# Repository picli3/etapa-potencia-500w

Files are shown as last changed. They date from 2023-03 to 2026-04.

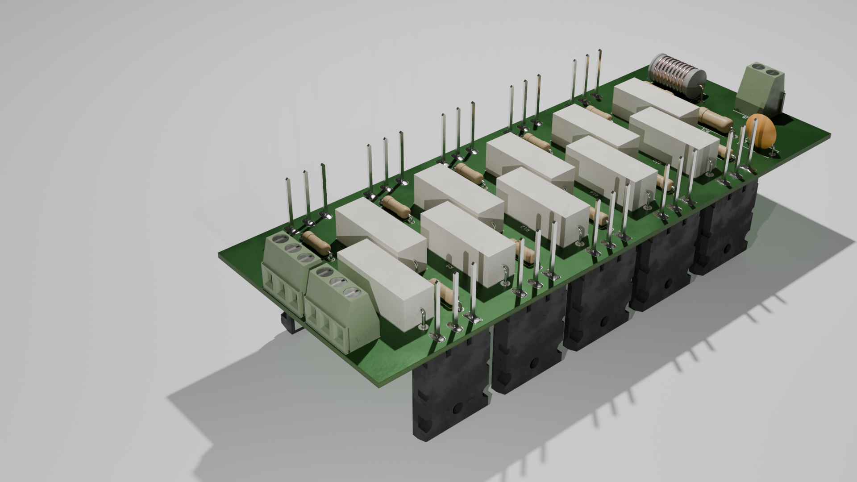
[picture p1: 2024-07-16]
doc/etapa-de-potencia_5.png

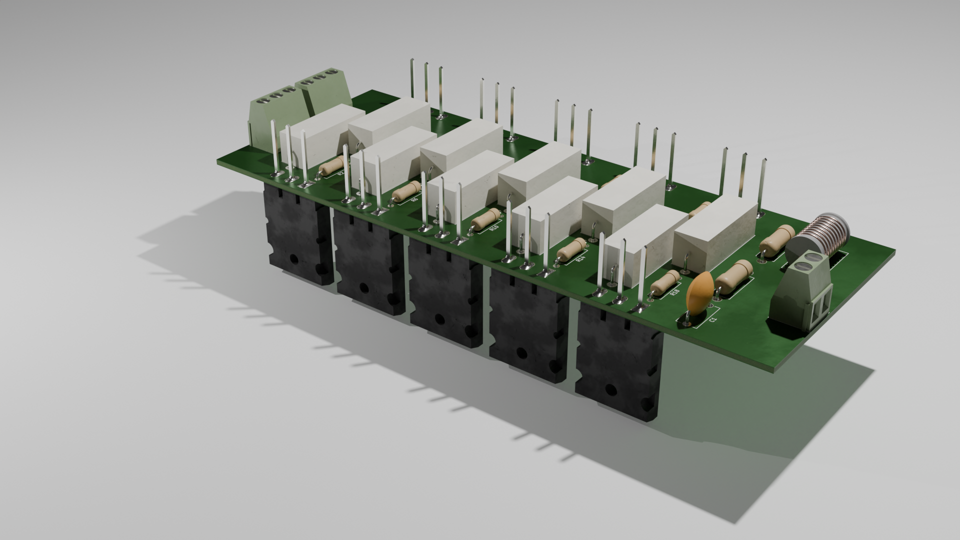
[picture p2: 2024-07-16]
doc/etapa-de-potencia_4.png

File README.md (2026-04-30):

# etapa-potencia-500w

Barra de potencia de audio con múltiples transistores en paralelo, pensada para entregar alta corriente y robustez térmica en amplificadores de gran potencia.

## Qué incluye
- esquemáticos o archivos de diseño en KiCad
- PCB o documentación asociada
- base reutilizable para análisis, fabricación o mejora del proyecto

## Propósito general
Este repositorio busca concentrar el diseño de hardware del proyecto en un formato editable y reutilizable, facilitando pruebas, documentación y futuras iteraciones del circuito.

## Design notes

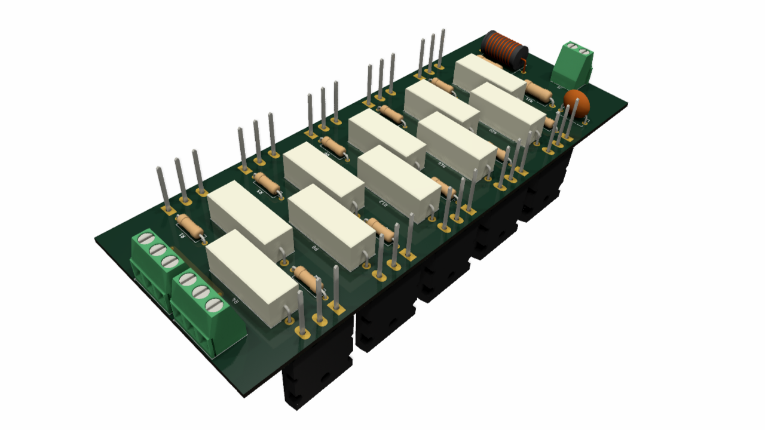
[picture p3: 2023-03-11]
doc/etapa-de-potencia_1.png

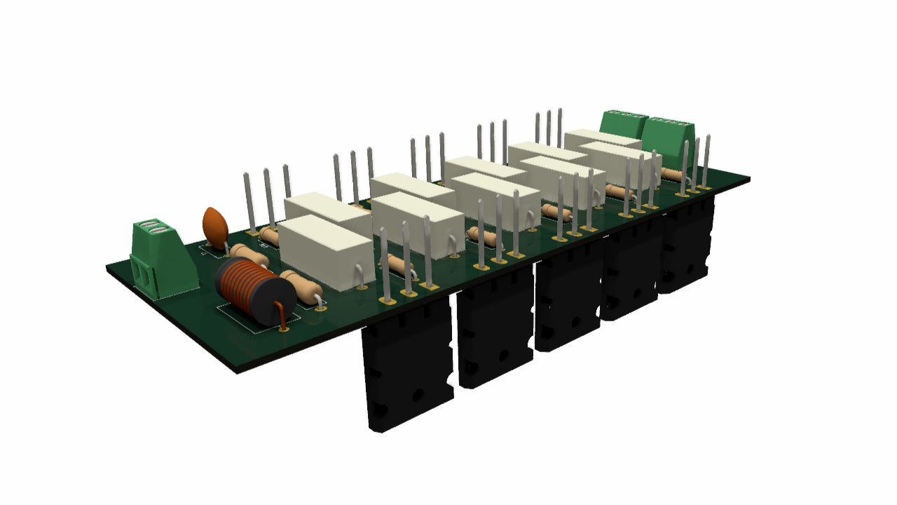
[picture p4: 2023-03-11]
doc/etapa-de-potencia_3.png

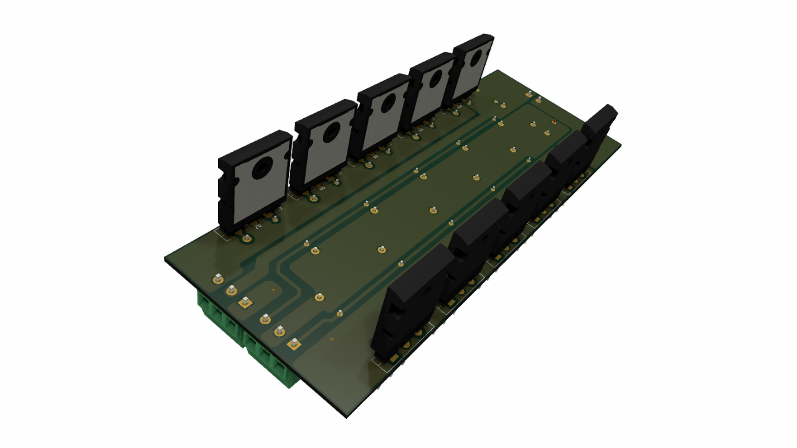
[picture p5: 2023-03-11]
doc/etapa-de-potencia_2.png

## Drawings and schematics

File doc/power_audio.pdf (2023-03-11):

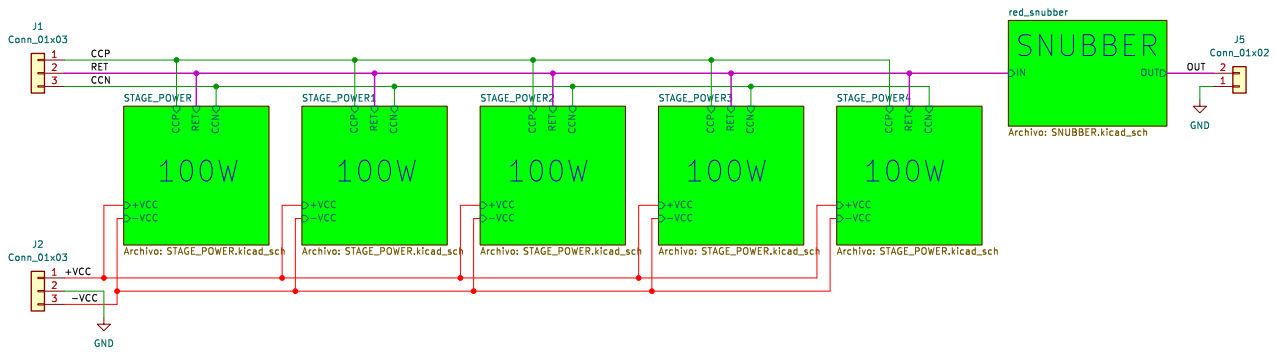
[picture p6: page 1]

Sheet: https://maykolrey.com

Id: 1/7 Title: Barra de potencia

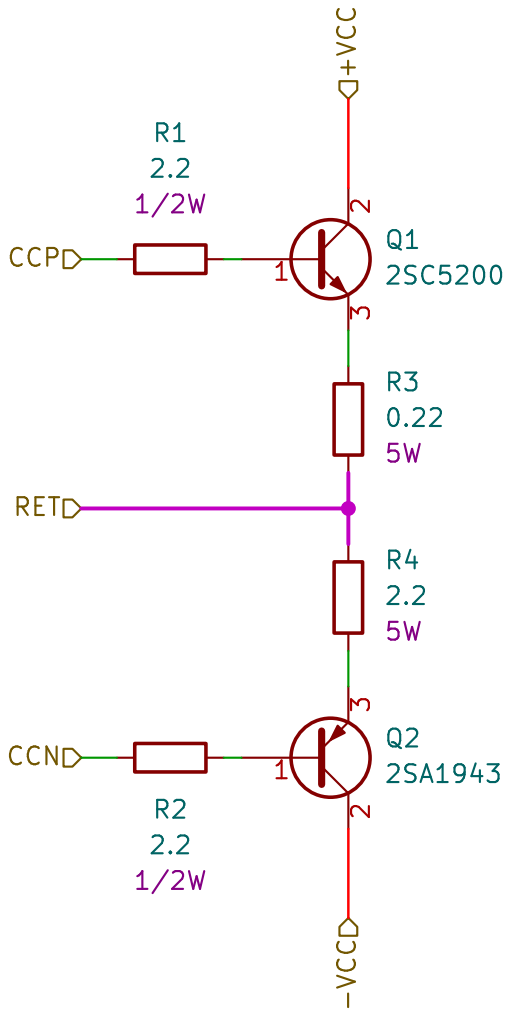
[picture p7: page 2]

https://maykolrey.com
Sheet: STAGE_POWER
Id: 2/7 Title: Barra de potencia

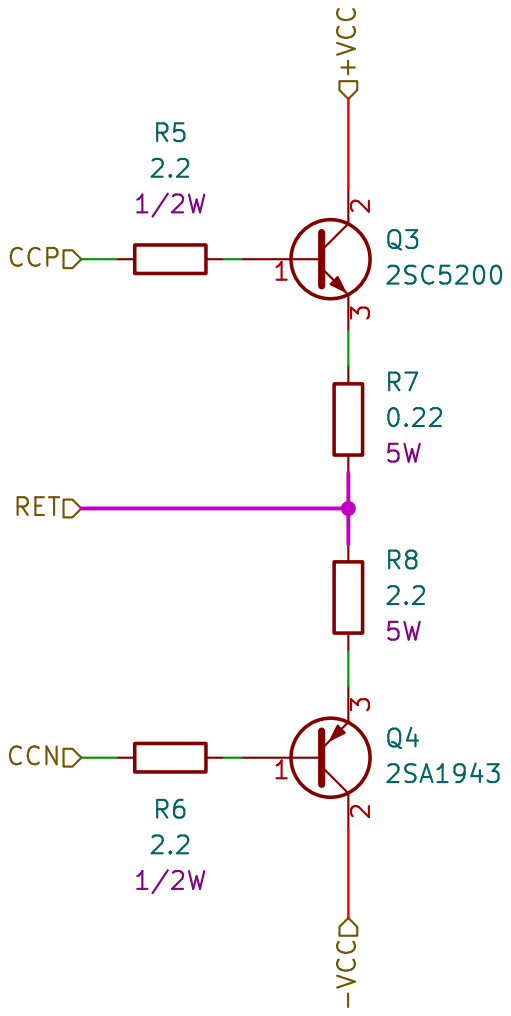
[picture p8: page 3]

https://maykolrey.com
Sheet: STAGE_POWER1
Id: 3/7 Title: Barra de potencia

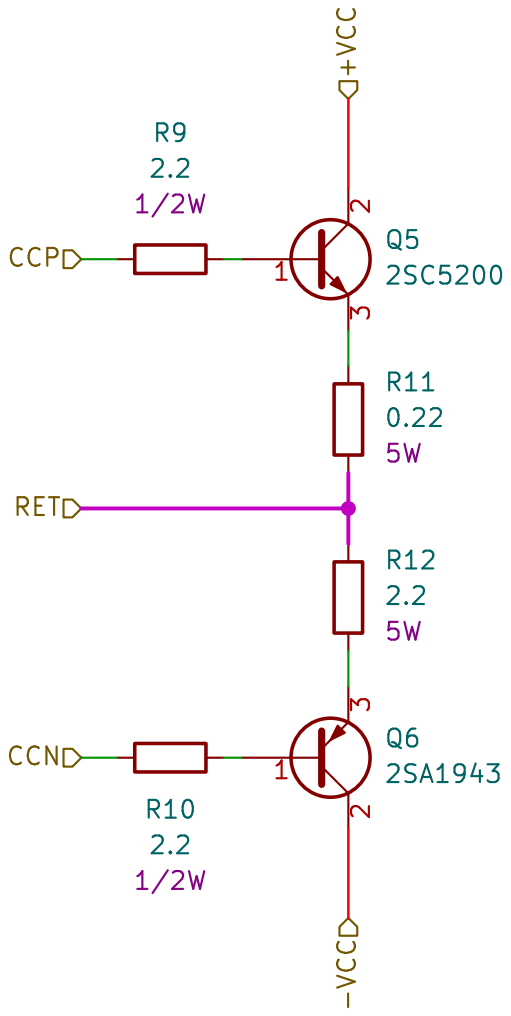
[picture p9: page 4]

https://maykolrey.com
Sheet: STAGE_POWER2
Id: 4/7 Title: Barra de potencia

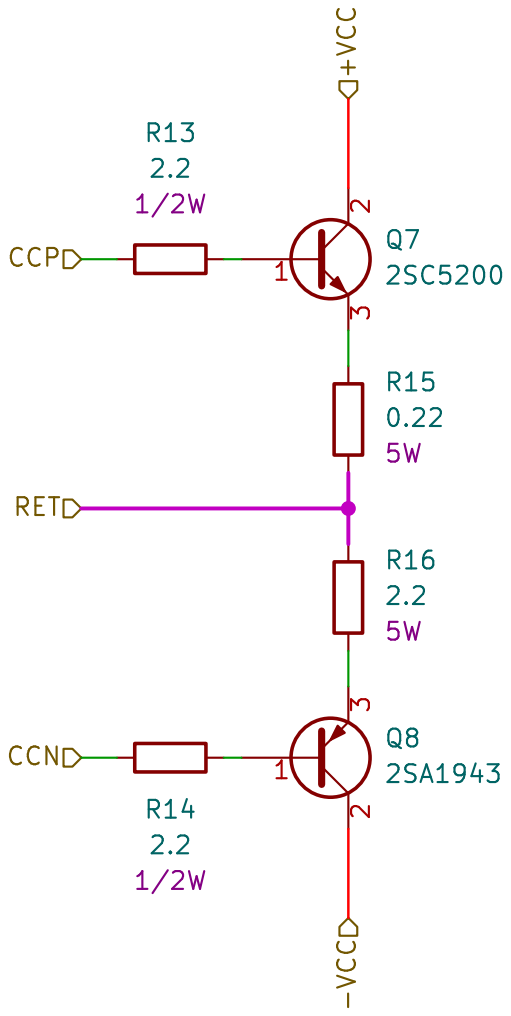
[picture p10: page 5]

https://maykolrey.com
Sheet: STAGE_POWER3
Id: 5/7 Title: Barra de potencia

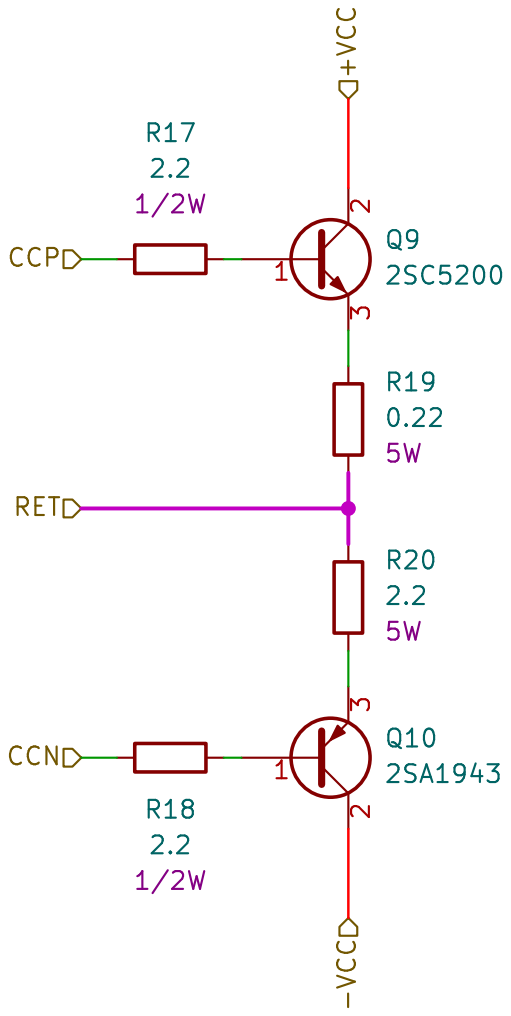
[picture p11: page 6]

https://maykolrey.com
Sheet: STAGE_POWER4
Id: 6/7 Title: Barra de potencia

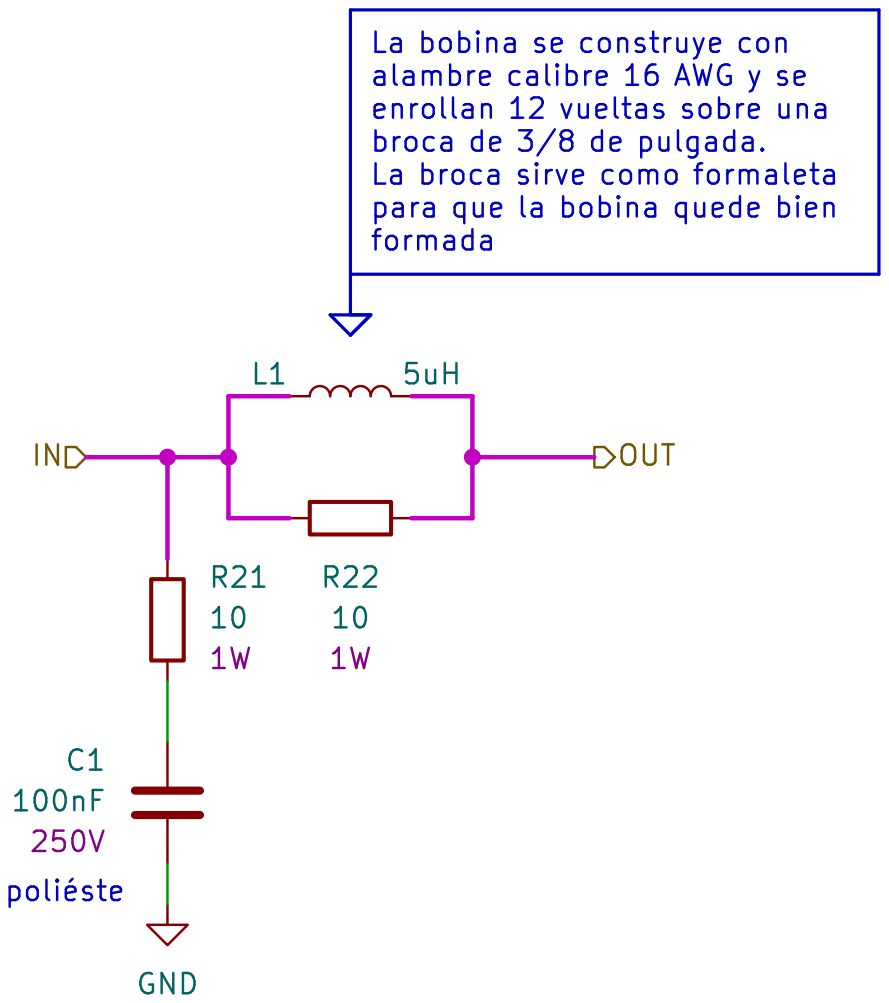
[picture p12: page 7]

La bobina se construye con
alambre calibre 16 AWG y se
enrollan 12 vueltas sobre una
broca de 3/8 de pulgada. La broca sirve como formaleta

para que la bobina quede bien
formada

https://maykolrey.com
Sheet: red_snubber
Id: 7/7 Title: Barra de potencia

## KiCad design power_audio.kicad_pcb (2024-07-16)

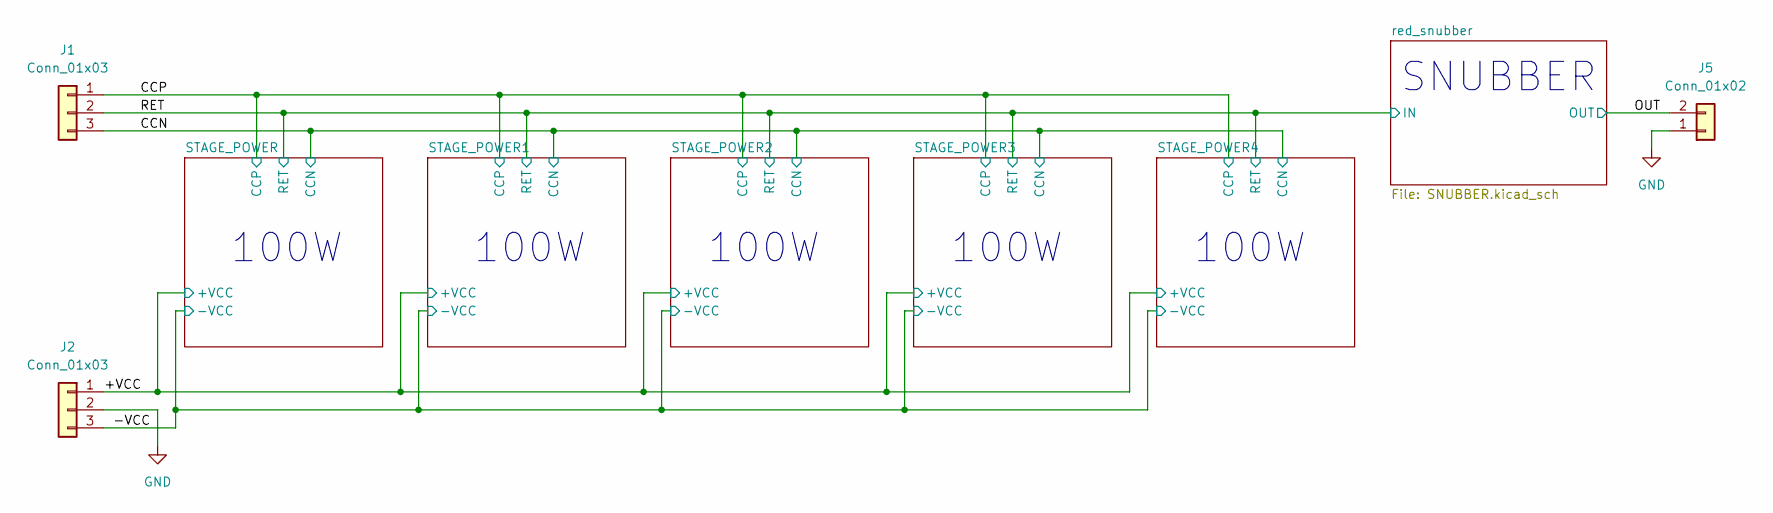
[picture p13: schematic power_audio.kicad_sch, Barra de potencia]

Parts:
J1, J2: Conn_01x03; TerminalBlock_Phoenix_MKDS-1,5-3-5.08_1x03_P5.08mm_Horizont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
J5: Conn_01x02; TerminalBlock_Phoenix_MKDS-1,5-2-5.08_1x02_P5.08mm_Horizont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

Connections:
/+VCC: J2.1; also elsewhere on the board
/-VCC: J2.3; also elsewhere on the board
/CCN: J1.3; also elsewhere on the board
/CCP: J1.1; also elsewhere on the board
/OUT: J5.2; also elsewhere on the board
/RET: J1.2; also elsewhere on the board
GND: J2.2, J5.1; also elsewhere on the board

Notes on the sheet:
100W
SNUBBER

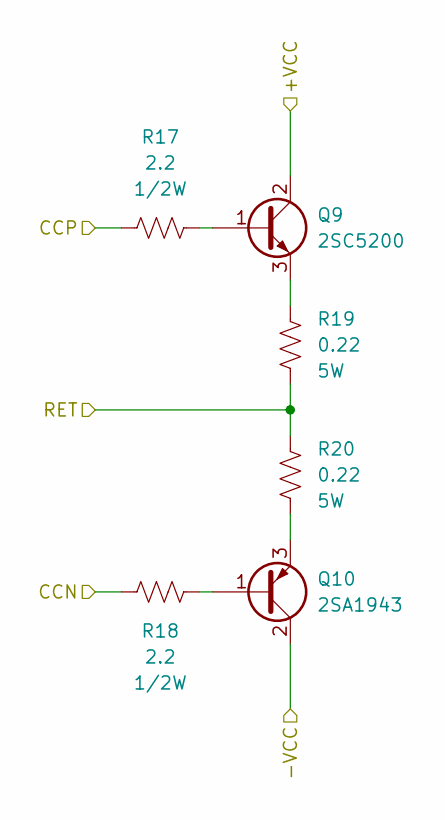
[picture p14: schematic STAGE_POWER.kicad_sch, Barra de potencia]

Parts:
Q9: 2SC5200; TO-264-3_Vertical; Mfr. Part 2SC5200OTU; LCSC Part C2920870
Q10: 2SA1943; TO-264-3_Vertical; Mfr. Part 2SA1943-O(Q); LCSC Part C480004
R17, R18: 2.2; R_Axial_DIN0309_L9.0mm_D3.2mm_P12.70mm_Horizontal
R19, R20: 0.22; R_Axial_Power_L25.0mm_W9.0mm_P27.94mm

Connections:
/+VCC: Q9.2 (C); also elsewhere on the board
/-VCC: Q10.2 (C); also elsewhere on the board
/CCN: R18.1; also elsewhere on the board
/CCP: R17.1; also elsewhere on the board
/RET: R19.1, R20.2; also elsewhere on the board
unnamed: Q9.1 (B), R17.2
unnamed: Q9.3 (E), R19.2
unnamed: Q10.1 (B), R18.2
unnamed: Q10.3 (E), R20.1

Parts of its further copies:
Q1, Q3, Q5, Q7: 2SC5200; TO-264-3_Vertical; Mfr. Part 2SC5200OTU; LCSC Part C2920870
Q2, Q4, Q6, Q8: 2SA1943; TO-264-3_Vertical; Mfr. Part 2SA1943-O(Q); LCSC Part C480004
R1, R2, R5, R6, R9, R10, R13, R14: 2.2; R_Axial_DIN0309_L9.0mm_D3.2mm_P12.70mm_Horizontal
R3, R7, R11, R15: 0.22; R_Axial_Power_L25.0mm_W9.0mm_P27.94mm

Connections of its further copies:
/+VCC: Q1.2 (C), Q3.2 (C), Q5.2 (C), Q7.2 (C); also elsewhere on the board
/-VCC: Q2.2 (C), Q4.2 (C), Q6.2 (C), Q8.2 (C); also elsewhere on the board
/CCN: R2.1, R6.1, R10.1, R14.1; also elsewhere on the board
/CCP: R1.1, R5.1, R9.1, R13.1; also elsewhere on the board
/RET: R3.1, R7.1, R11.1, R15.1; also elsewhere on the board
unnamed: Q1.1 (B), R1.2
unnamed: Q1.3 (E), R3.2
unnamed: Q2.1 (B), R2.2
unnamed 11: Q2.3 (E); also elsewhere on the board
unnamed: Q3.1 (B), R5.2
unnamed: Q3.3 (E), R7.2
unnamed: Q4.1 (B), R6.2
unnamed 15: Q4.3 (E); also elsewhere on the board
unnamed: Q5.1 (B), R9.2
unnamed: Q5.3 (E), R11.2
unnamed: Q6.1 (B), R10.2
unnamed 19: Q6.3 (E); also elsewhere on the board
unnamed: Q7.1 (B), R13.2
unnamed: Q7.3 (E), R15.2
unnamed: Q8.1 (B), R14.2
unnamed 23: Q8.3 (E); also elsewhere on the board

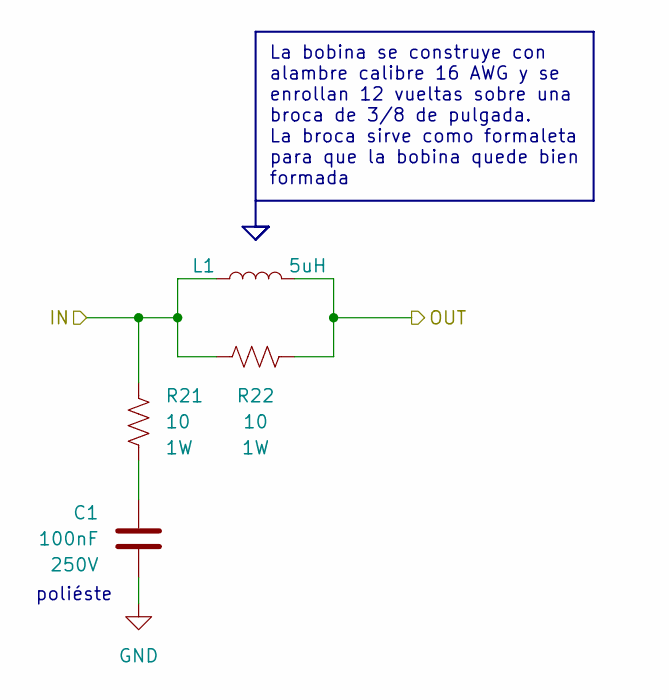
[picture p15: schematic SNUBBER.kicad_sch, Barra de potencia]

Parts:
C1: 100nF; C_Disc_D10.5mm_W5.0mm_P10.00mm; VOLTAGE 250V
L1: 5uH; L_Axial_L16.0mm_D9.5mm_P20.32mm_Horizontal_Vishay_IM-10-37
R21, R22: 10; R_Axial_DIN0414_L11.9mm_D4.5mm_P15.24mm_Horizontal

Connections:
/OUT: L1.2, R22.2; also elsewhere on the board
/RET: L1.1, R21.2, R22.1; also elsewhere on the board
GND: C1.2; also elsewhere on the board
unnamed: C1.1, R21.1

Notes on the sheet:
La bobina se construye con alambre calibre 16 AWG y se enrollan 12 vueltas sobre una broca de 3/8 de pulgada. La broca sirve como formaleta para que la bobina quede bien formada
poliéste

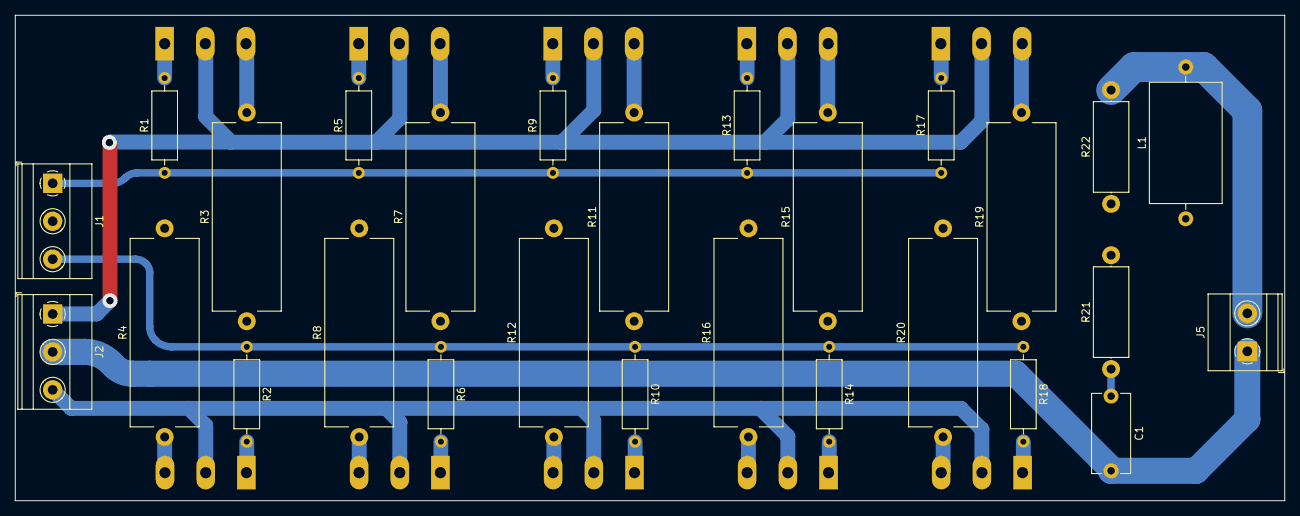
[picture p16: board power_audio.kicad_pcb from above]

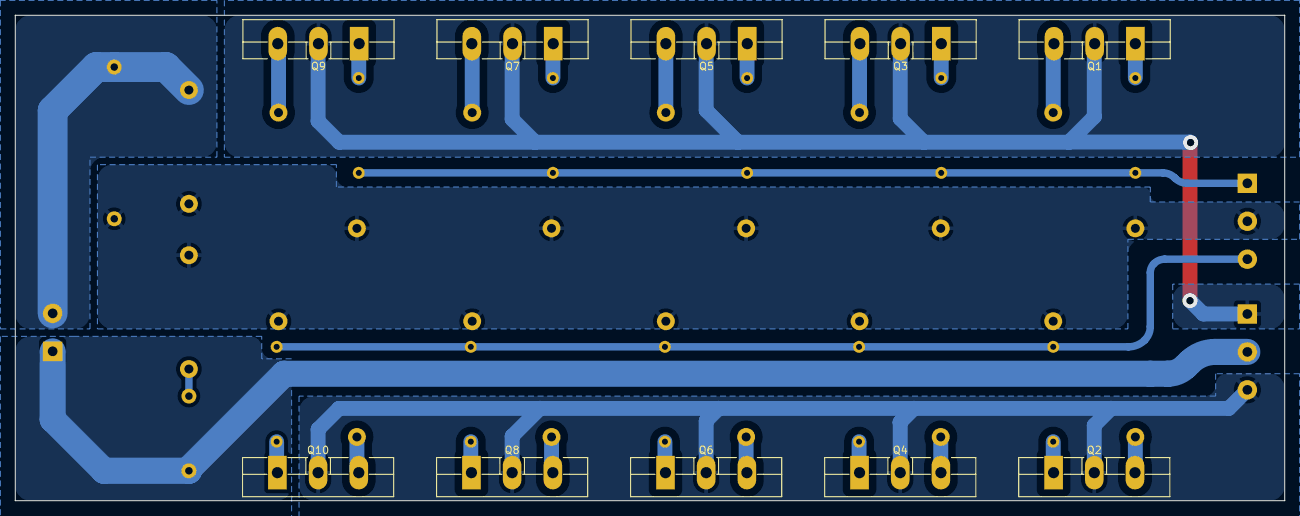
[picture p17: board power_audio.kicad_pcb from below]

Board: 2 copper layers, 170.0 x 65.0 mm, 37 parts (10 on the bottom side), 28 nets.

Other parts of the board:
R4, R8, R12, R16: 2.2; R_Axial_Power_L25.0mm_W9.0mm_P27.94mm

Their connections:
/RET: R4.2, R8.2, R12.2, R16.2; also elsewhere on the board
unnamed 11: R4.1; also elsewhere on the board
unnamed 15: R8.1; also elsewhere on the board
unnamed 19: R12.1; also elsewhere on the board
unnamed 23: R16.1; also elsewhere on the board

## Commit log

2023-03-11 agregando etapa de potencia
    [SNUBBER.kicad_sch, STAGE_POWER.kicad_sch, power_audio.kicad_pcb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]
2023-03-11 agregando el circuito
2024-07-16 mejorando pistas
    [SNUBBER.kicad_sch, STAGE_POWER.kicad_sch, power_audio.kicad_pcb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]
